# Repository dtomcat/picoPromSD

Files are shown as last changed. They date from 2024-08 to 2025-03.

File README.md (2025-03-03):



# picoPromSD
EEPROM reader/writer and OG Xbox Seagate Password retrieval for the Original Xbox that also decodes the EEPROM data

What will it do?

1. Backup the Xbox's EEPROM and save it to microSD card.
2. Can write an EEPROM backup saved to µSD card to the Xbox's EEPROM.  (has some checks to help prevent writing a bad backup to the EEPROM)
3. Decrypt the EEPROM and save the important information in plain text to the µSD card.
4. Can calculate the HDD password while backing up the EEPROM (for OEM Seagate and WD drives)
		- Requires preparing an additional file.  Video of process: [Video of Process](https://youtu.be/JSXaQWXcwFo?si=bOLGbLG80aQxxA59)
5. For OEM Seagate drives (ALL), It can grab the HDD password directly from the drive itself.  No need for EEPROM or XBOX.  [Video of Process](https://youtu.be/1lWm_fr0Neo?si=kcM-wwt6UB56qRjm)
6. For OEM Seagate drives (ALL), It can unlock the HDD directly from the drive itself.  No need for EEPROM or XBOX.  [Video of Slim](https://www.youtube.com/shorts/Nwhjg9Vyvl8), [Video of RJ](https://www.youtube.com/shorts/swidWJ0N5yo)
7. More features may be added later.
<br><br><br>
This project is based on the work from Ryzee119's ArduinoProm:

>ArduinoProm. An Arduino based Original Xbox EEPROM reader and writer.
>It can be used to recover a HDD key etc. <br><br>
>ArduinoProm is inspired and adapted upon the awesome work by Grimdoomer on PiPROM, now achievable on a <$3 Arduino board.
>See https://github.com/grimdoomer/PiPROM for the Original Raspberry Pi version!
>  
>**Use at your own risk**
>

>The firmware has been written around the Arduino Pro Micro Leonardo (5V/16Mhz). However I would expect it to work on any Arduino with a built in USB >bootloader/Virtual Comport support, and obviously I2C support.
>1. Open `ArduinoProm.ino` in [Arduino IDE](https://www.arduino.cc/en/main/software)
>2. Connect your Arduino to your PC and setup the IDE. An example below <br> Arduino IDE preview
>3. Hit the program button then confirm it compiles and programs successfully.
>
>
>By Ryzee119

This project uses code by Ryzee119, dx4m (from this [project](https://github.com/dx4m/Xbox-EEPROM-Utility)), and may contain code from various snippets from different forums (sorry lost my notes on who to thank).

This project is a continuation of my work from [ArdPromSD project](https://github.com/dtomcat/ArdPromSD).
This project was moved to an RP2040 MCU for more memory space.  This allowed me add the features I wanted to from the previous project, but ran out of program space to do so.  New features include better logging, eeprom decryption, as well as being able to retrieve the password from OEM seagate drives without the need for the original eeprom, original xbox, or even a PC!

SPECIAL THANKS!!!!<br>
Ryzee for his project above!<br>
Skye for all the HDD commands and knowledge! Invaluable addition to PPSD!<br>
Beta Testers:  Cato, Harcroft, Siktah

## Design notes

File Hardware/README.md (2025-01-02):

1.1 is the initial released version.  Those who backed the initial project and funded it have a limited edition 1.0a version (Thank you!).  This will not be released and is solely for the limited backers.  1.1 just has minor trace redesigns and the "Advanced users" port has been removed.  Version 1.5H has already been designed and as soon as it's tested, It will be uploaded.  I do not recommend building rev 1.1 as 1.5H has major changes to the board to allow for lower cost builds.  Functionally, they will be the same.  Enjoy!<br><br>

# Rev 1.1 - 12DEC2024
Initial Release (No Gerbers or Assembly info for this release.  1.5H and above will have them.)

# Rev 1.5H - 02JAN2025
Happy New Year!  1.5H released (rework done by Harcroft - Thank you!  Allows for lower cost build with same quality and funcionality) This is a full release with everything you need to build one, or have one assembled.

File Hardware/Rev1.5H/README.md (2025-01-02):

## Initial release of picoPromSD
Initial release that contains everything needed to either make or have one assembled
This revision is an edit from the first release.  All edits were done by Harcroft who put a lot of time in effort into find same quality alternate parts at lower costs so picoPromSD could be build at a lower cost without sacrificing quality or functionality! <br><br>

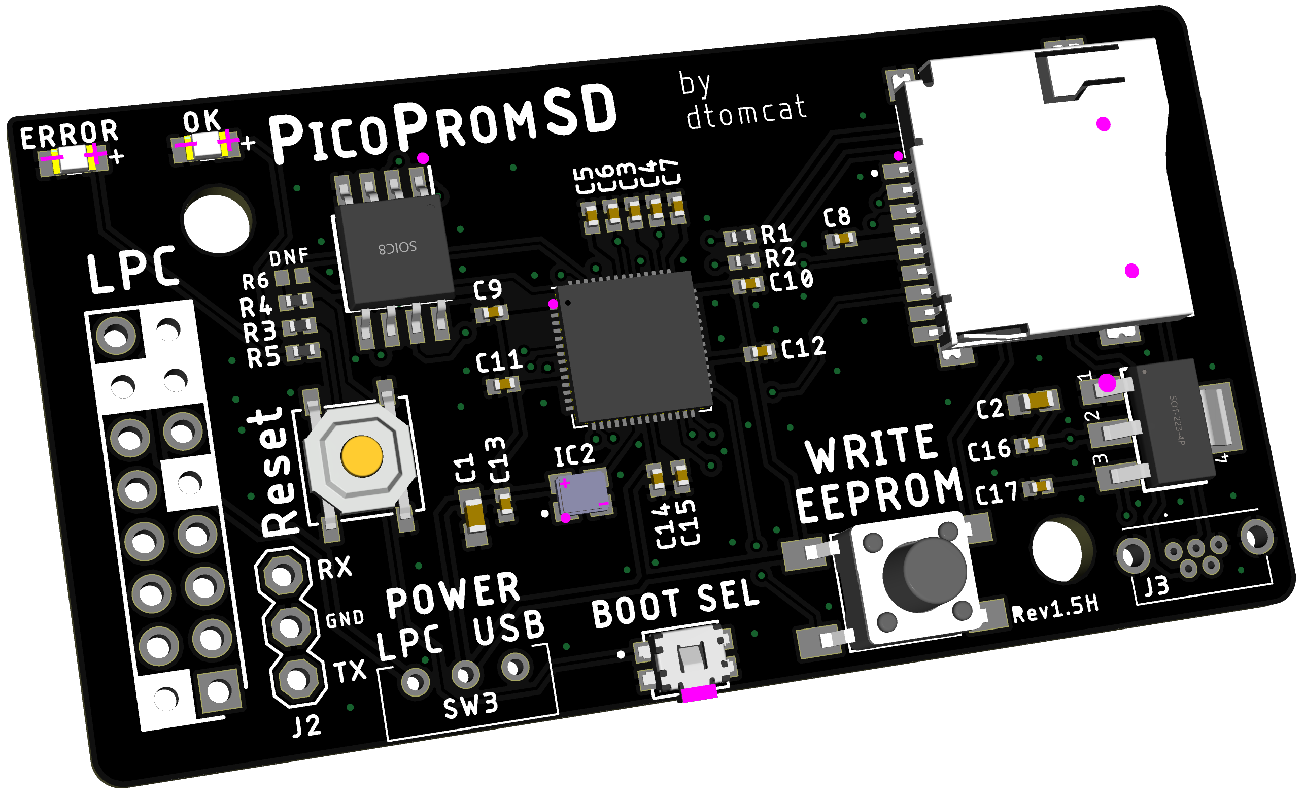
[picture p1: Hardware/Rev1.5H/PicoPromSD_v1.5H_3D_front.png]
picoPromSD
<br>
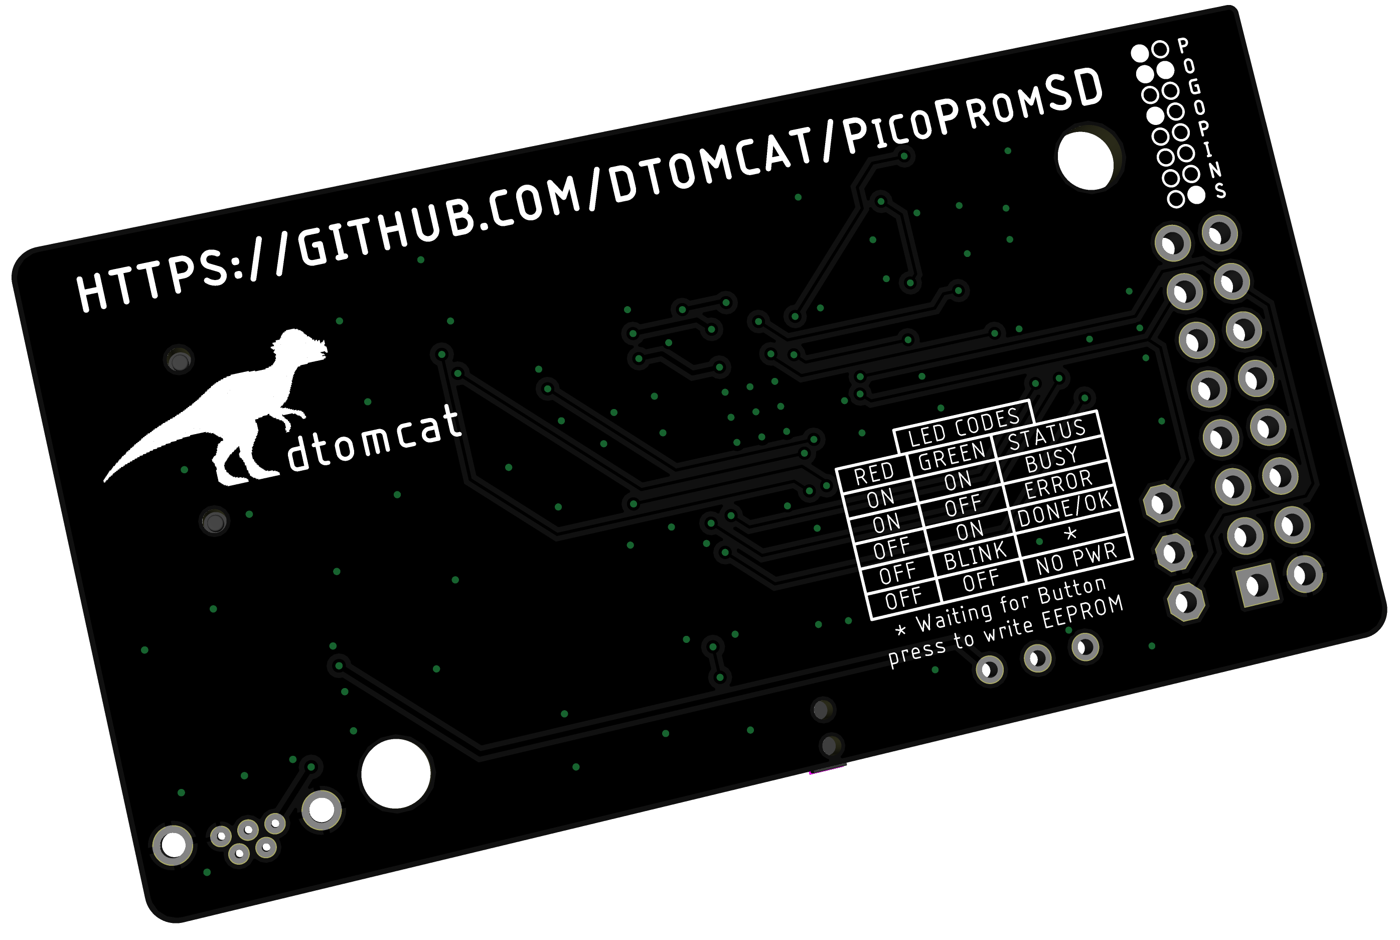
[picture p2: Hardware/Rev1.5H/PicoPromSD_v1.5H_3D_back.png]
picoPromSD
<br>

In the main Rev1.5H directory are all the files to edit the board as you want including library of all components.

### Gerbers
- Contains all files necessary to have the PCBs made at your preferred PCB house.<br><br>

### Assembly
- Contains all files necessary to have the PCBs made and assemble at your preferred PCB house. (was made for JLCPCB, but may work with others)
    - [PicoPromSD_v1.5H_JLC_PCBA_BOM.xlsx](Assembly/PicoPromSD_v1.5H_JLC_PCBA_BOM.xlsx) and [PicoPromSD_v1.5H_top_JLC_CPL.csv](Assembly/PicoPromSD_v1.5H_top_JLC_CPL.csv) are the files JLCPCB will ask for when selecting assembly.
    - [PicoPromSD_v1.5H_LCSC_THT_BOM.xlsx](Assembly/PicoPromSD_v1.5H_LCSC_THT_BOM.xlsx) is the parts you'll need (from LCSC) that are not a part of the assembly and will need to be hand soldered on.  These are through hole components and were purposely omitted from the assembly to save costs since through hole adds a considerable amount to assembly costs.
    - [PicoPromSD_v1.5H_Digikey_BOM.xlsx] contains a full BOM to allow you to order all the parts and hand assemble the entire board. (or would just like to use parts from Digikey instead of LCSC).

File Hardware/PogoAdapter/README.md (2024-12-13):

This is the STL for the pogoadapter.  Uses a 2x08 pin header and 5 pogo pins.   Highly recommend P75-E3 pogo pins.

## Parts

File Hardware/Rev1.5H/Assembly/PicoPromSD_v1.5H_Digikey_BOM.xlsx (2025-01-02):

Digikey Part Number | Quantity | Manufacturer Part Number | Customer Reference | Description | Pack Type 1
2648-SC0914(13)CT-ND | 1 | SC0914(13) | IC1 | IC MCU 32BIT EXT MEM 56QFN | Cut Tape (CT)
XC1426CT-ND | 1 | ECS-2033-120-BN | IC2 | XTAL OSC XO 12.0000MHZ CMOS SMD | Cut Tape (CT)
W25Q32JVSSIQ-ND | 1 | W25Q32JVSSIQ | IC3 | IC FLASH 32MBIT SPI/QUAD 8SOIC | Tube
497-1241-1-ND | 1 | LD1117S33CTR | IC4 | IC REG LINEAR 3.3V 800MA SOT223 | Cut Tape (CT)
2223-MSD-4-ACT-ND | 1 | MSD-4-A | J1 | MICRO SD CARD CONNECTOR, 9 POSIT | Cut Tape (CT)
2223-TS04-66-70-BK-100-SMT-ND | 1 | TS04-66-70-BK-100-SMT | SW1 | SWITCH TACTILE SPST-NO 0.05A 12V | Bag
CKN12221-1-ND | 1 | PTS526SK15SMTR2 LFS | SW2 | SWITCH TACTILE SPST-NO 0.05A 12V | Cut Tape (CT)
4809-SKSCLBE010CT-ND | 1 | SKSCLBE010 | SW4 | SWITCH TACTILE SPST-NO 0.05A 12V | Cut Tape (CT)
732-4986-1-ND | 1 | 150080VS75000 | GLED | LED GREEN CLEAR 0805 SMD | Cut Tape (CT)
732-4984-1-ND | 1 | 150080RS75000 | RLED | LED RED CLEAR 0805 SMD | Cut Tape (CT)
1276-1192-1-ND | 10 | CL10A106KP8NNNC | C1, C2 | CAP CER 10UF 10V X5R 0603 | Cut Tape (CT)
1276-1010-1-ND | 10 | CL05A105KQ5NNNC | C3, C4 | CAP CER 1UF 6.3V X5R 0402 | Cut Tape (CT)
1276-1001-1-ND | 20 | CL05B104KO5NNNC | C5 - C17 | CAP CER 0.1UF 16V X7R 0402 | Cut Tape (CT)
YAG3085CT-ND | 10 | RC0402FR-0727R4L | R1, R2 | RES 27.4 OHM 1% 1/16W 0402 | Cut Tape (CT)
311-820LRCT-ND | 10 | RC0402FR-07820RL | R3 | RES 820 OHM 1% 1/16W 0402 | Cut Tape (CT)
311-1.00KLRCT-ND | 10 | RC0402FR-071KL | R4, R5 | RES 1K OHM 1% 1/16W 0402 | Cut Tape (CT)
1849-1003-ND | 1 | PR20203VBNN | J2 | CONN HEADER VERT 3POS 2.54MM | Bag
2073-USB3145-30-1-ACT-ND | 1 | USB3145-30-1-A | J3 | MICRO B SKT, VERTICAL, TH, 30", | Cut Tape (CT)
732-61301621821-ND | 1 | 61301621821 | LPC | WR-PHD 2.54 MM DUAL SOCKET HEADE | Tray
679-1849-ND | 1 | MHSS1105 | SW3 | SWITCH SLIDE SPDT 300MA 6V | Bulk

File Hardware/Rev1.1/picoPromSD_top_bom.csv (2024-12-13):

Comment | Designator | Footprint | LCSC Part #
1K | GLED R5 R6 RLED R4 | R0402
1u | C1 C4 | C0402
10uF | C18 | C0603
27R | R1 R2 | R0402
100n | C2 C3 C5 C6 C7 C8 C9 C10 C11 C12 C13 C14 C15 C16 C17 | C0402
DNF 10K | R3 | R0402
EVQ-P7A01P | S4 | EVQP7J01P
LD1117S33TR | IC4 | SOT223
MEM2075-00-140-01-A | J1 | MEM20750014001A
RP2040-QFN56 | IC1 | RP2040-QFN-56
SIT2001B | IC2 | SOT95P280X130-5N
TL6330AF200Q | S2 | TL6330AF200Q
TS04-66-70-BK-100-SMT | S1 | SW_TS04-66-70-BK-100-SMT
W25Q32JVSSIQ_TR | IC3 | SOIC127P790X216-8N

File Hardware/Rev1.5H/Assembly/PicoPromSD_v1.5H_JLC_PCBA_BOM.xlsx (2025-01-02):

Comment | Designator | Footprint | JLCPCB Part #（optional）
RP2040 | IC1 | LQFN-56(7x7) | C2040
S2D12.000000B20F30T | IC2 | SMD2520-4P | C387449
W25Q32JVSSIQ | IC3 | SOIC-8-208mil | C82344
LD1117S33CTR | IC4 | SOT-223-4 | C35879
WQ21801-B2180-7F | J1 | SMD | C2836427
TS-1102SD-A-G-R | SW1 | SMD | C3010210
GT-TC084B-H015-L5 | SW2 | SMD | C778173
SKSCLBE010 | SW4 | SMD | C115361
KT-0805G | GLED | 0805 | C2297
NCD0805R1 | RLED | 0805 | C84256
CL10A106KP8NNNC | C1,C2 | 0603 | C19702
CL05A105KA5NQNC | C3,C4 | 0402 | C52923
CL05B104KO5NNNC | C5,C6,C7,C8,C9,C10,C11,C12,C13,C14,C15,C16,C17 | 0402 | C1525
RC0402FR-0727R4L | R1,R2 | 0402 | C274349
RC0402FR-07820RL | R3 | 0402 | C137933
0402WGF1001TCE | R4,R5 | 0402 | C11702

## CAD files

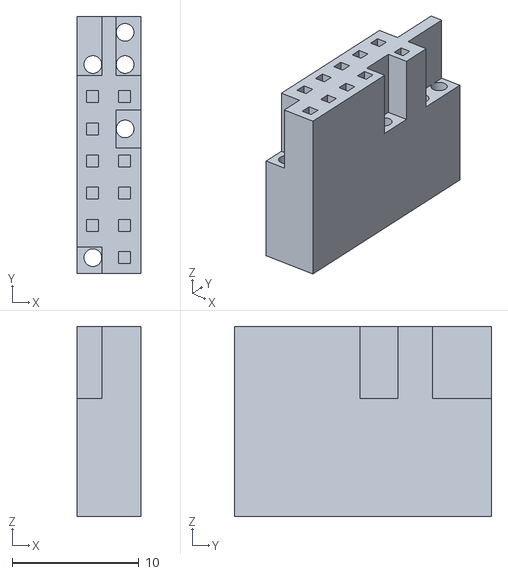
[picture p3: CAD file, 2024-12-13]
Hardware/PogoAdapter/Pin2PogoPico v3.stl
5.04 x 20.3 x 15.0

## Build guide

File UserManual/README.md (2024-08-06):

Still a work in progress... (Pogo Pin Section needs updated, need to add a lot more info)

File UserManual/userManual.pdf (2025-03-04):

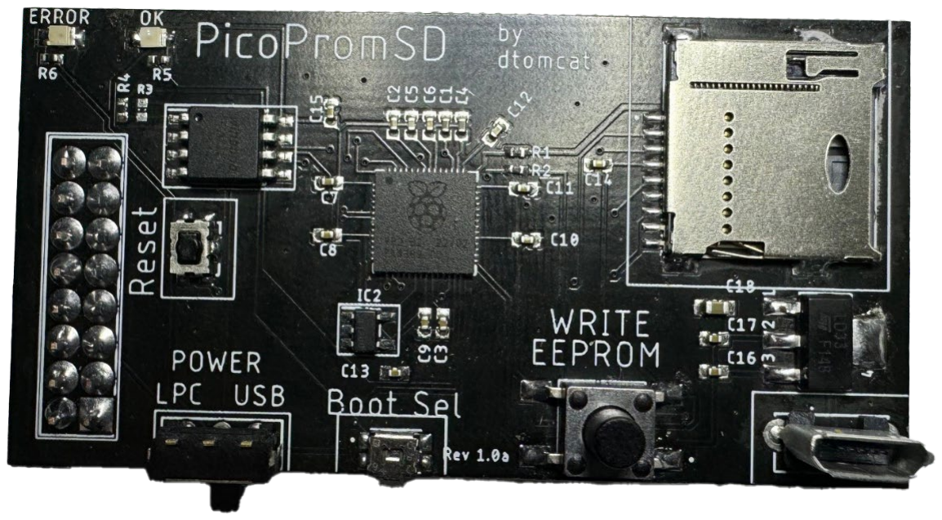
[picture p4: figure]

# PicoPromSD User Manual

## Version 1.0

01/04/2024

Pachy Software | Introduction
UM Version 1.0 | 2 | PicoPromSD

Table of Contents

Pachy Software | Introduction
UM Version 1.0 | 3 | PicoPromSD

# 1. Introduction

This User Manual (UM) provides the information necessary for effective use of PicoPromSD.

## 1.1 Overview

The PicoPromSD was designed as a tool to backup and restore EEPROM data in the original Microsoft Xbox. Upon plugging in the PicoPromSD into the Xbox’s LPC port, it will automatically backup the EEPROM data to inserted microSD card in the “EPBACKUP” folder. This only takes a second. If an “eeprom.bin” file is found in the “WRITEEP” folder, you will be given the option to write that file onto the EEPROM chip on the Xbox motherboard. Ensure you read over this entire manual before using your PicoPromSD for the first time.

Pachy Software | Getting Started
UM Version 1.0 | 4 | PicoPromSD

# 2. Getting Started

## 2.1 Cautions & Warnings

This tool has the potential to damage your Xbox and turn it into a paperweight. If mishandled, it could corrupt your EEPROM which could cause the Xbox to no longer function. You take all the risks associated with using the PicoPromSD and no guarantees are made.

## USE AT YOUR OWN RISK

## 2.2 Set-up Considerations

To use PicoPromSD, you will need a microSD card that is formatted with FAT32 filesystem. FAT16 should also work but not tested.
You will be required to disassemble your Xbox (not covered in the manual) to access the LPC port on your Xbox.
The easiest way to use PicoPromSD, is to have a 2x8 pin header soldered into the Xbox’s LPC port. While this is not necessary, it will allow the safest and easiest connection. The LPC port does not have to be rebuilt for 1.6 versions of motherboards; however, if soldering a pin header onto the motherboard, it’s recommended to go ahead with the rebuild for future use.

Pachy Software | Using the System

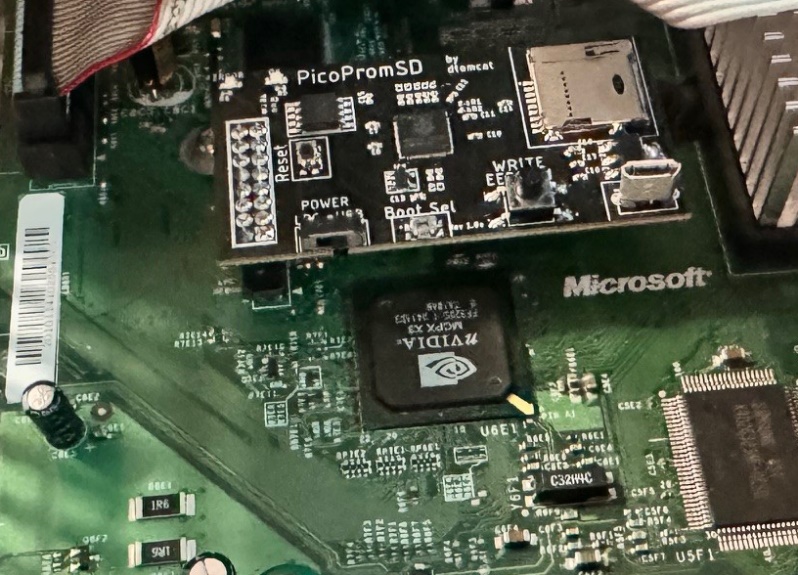
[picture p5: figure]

UM Version 1.0 | 5 | PicoPromSD

# 3. Using the System

The following sub-sections provide step-by-step instructions on how to use the various functions or features of the PicoPromSD. Figure 2 in this section will identify the LEDs mentioned in this section.

## 3.1 Backing up the EEPROM

Backing up the EEPROM is easy and requires very little from the user. This guide will assume your LPC port on your Xbox has a pin header installed as recommended in section 2.2.
1. Insert the FAT32/FAT16 formatted microSD card into the PicoPromSD
2. With the Xbox POWERED OFF and Power switch is on USB (to the right), place the PicoPromSD onto the pin header on the LPC port. Place it so that the microSD and button are on the right-hand side of the LPC port and are closer to the center of the Xbox’s motherboard (see Figure 1).
3. Power on the Xbox.
a. After power is stable (if D0/LFrame is grounded, let the Xbox FRAG), Flip the power switch on the PicoPromSD to LPC.
b. When power is applied, you will see both the green and red LEDs light up. This means that the backup is in process.
c. After a second, the red LED will go out and the green will stay on. This means that the backup was successful. If the green LED goes out and red stays on, then there was an error. Check the microSD card and try again. If the problem persists, check the log written to the SD for possible errors. If no log has been written, then the SD card may be the issue.
4. Turn off power to your Xbox and flip the power switch to USB, then remove the PicoPromSD.
a. Your backup will be on the microSD card under the epbackup folder. You can backup multiple times. Each backup name is incremented, so you can backup multiple systems without needing to change microSD card. (Backups are named the Xbox’s Serial number or eeprom.bin (if serial number cannot be determined), subsequent backups of same system will append a 1,2,3, etc… to the file name.)
5. Backup is complete.

Figure 1.

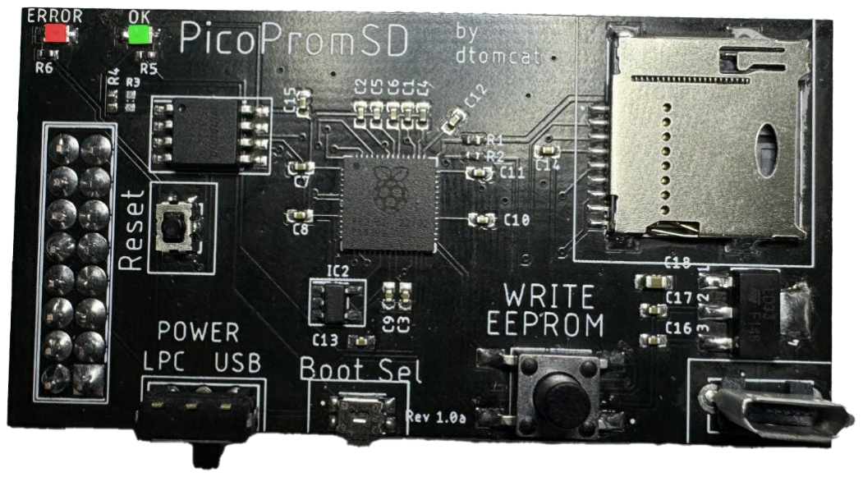
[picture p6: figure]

UM Version 1.0 | 6 | PicoPromSD

## 3.2 Writing to the EEPROM

Writing to your EEPROM is a little bit more involved (on purpose). It’s important to note that the PicoPromSD does not validate nor verify the eeprom.bin provided by you. If you provide a corrupt eeprom.bin, it will write the corrupt eeprom.bin and therefore… CORRUPT your EEPROM. Caution must be taken to ensure you provide a valid eeprom.bin.
Please note, that eeprom.bin file will be deleted from the “WRITEEP” folder (discussed later). The eeprom.bin files inside the EPBACKUP folder will not be touched. Please ensure you have a backup of the eeprom.bin file you place in the “WRITEEP” folder.
To write to your EEPROM:
1. On the microSD card you’re using
a. Create a new folder in the root directory named “WRITEEP”
b. Copy your eeprom.bin (that you validated and verified) into the “WRITEEP” folder.
c. Now follow the instructions in section 3.1 through 3.1.3. Do not turn off the Xbox. After 3.1.3, return here.
2. After the backup, if the microSD card was prepared correctly, the PicoPromSD’s green LED will flash rapidly. This informs you that it sees the eeprom.bin in the WRITEEP folder and is ready to write the EEPROM.
a. CAUTION: the next part can kill your Xbox. Do not proceed unless you know what you are doing. This will overwrite your EEPROM with the data you provided. If that data is corrupt… so will your EEPROM. PROCEED AT YOUR OWN RISK.
3. When ready to Write, and the green LED is flashing rapidly, Press the “WRITE EEPROM” button on the PicoPromSD.
a. When complete, the green LED is will stay on solid, and the write process is complete. NOTE: The eeprom.bin file is now deleted from the “WRITEEP” folder. This is to ensure you do not accidentally write that file to another Xbox.
4. Write Process is now complete.

Figure 2.

UM Version 1.0 | 7 | PicoPromSD

## 3.3 Reading/Writing the EEPROM without a Pin Header

It is possible to read from and write to your EEPROM without a pin header installed on your Xbox. One example will be given in this section (pogo pins). While reading from your EEPROM with this method is relatively safe, it is not recommended for writing to your EEPROM. This method basically uses pressure to make the electrical connections between the PicoPromSD and Xbox LPC port as you press the pogo pins into place. Reading data from the EEPROM is relatively quick and, if done incorrectly, results in an error or a corrupted eeprom.bin stored to the SD card. Writing data to the EEPROM is relatively time-consuming and requires a very stable electrical connection by comparison. Failing to write the EEPROM correctly will permanently damage your xbox. If enough pressure can be exerted the entire time (while pressing the “write EEPROM” button and throughout the entire process) this method can be used for reading and writing. Again… This process isn’t recommended for writing… and note the chance of your backup being corrupted as well.

## 3.3.1 Cautions with pogo pin method

CAUTIONS/WARNINGS:
1. If the pogo pins are not placed on the correct LPC port vias/pads, you can damage the PicoPromSD and/or your Xbox motherboard. Ensure proper placement. Damage can occur while the Xbox is powered OFF but plugged into a wall outlet.
2. Take care not to exert too much pressure on the pogo pins as damage to boards/pins can occur. Only enough force to compress the internal springs is needed.
3. Not exerting enough force will result in poor connection. During the reading stage… this can result in corrupted backup files. During the writing stage, this can cause damage to your Xbox resulting in the Xbox not being able to boot.
4. If the LPC appears dirty, You may need to clean the area to ensure a good electrical connection.

## 3.3.2 Making a Pogo Pin attachment

There are many ways to make a pogo pin attachment for the PicoPromSD. How you do so is up to you. There is a 3D model that can be printed to aid in this step.
You will need the following:
1. 1 3D printed part
2. 1 2x8 pin header
3. 5 Pogo pins (P75-E3 Spring Test Probe)
4. Soldering Iron/Solder
This requires soldering in small places. It is not recommended for those who are not comfortable with soldering. Heat and plastic do not mix! If you are not comfortable or careful, you will melt the plastic and may make the piece unusable.

### 3.3.2.1 Assembly Instructions

1. Insert pin header (use side with shorter pins) into 3D printed part. Use the side with square holes.
2. Insert pogo pins (end with smallest diameter) into opposite side of 3D printed part. Ensure the ends of pogo pins and pin header touch in the visible voids of 3D printed part.

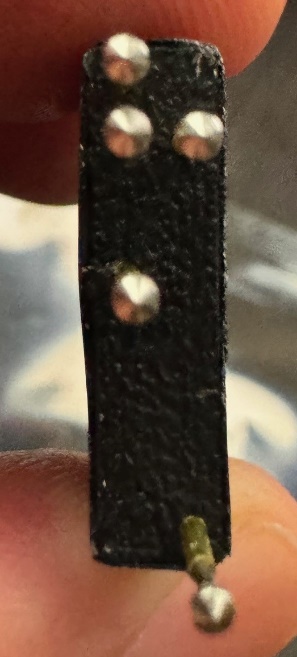
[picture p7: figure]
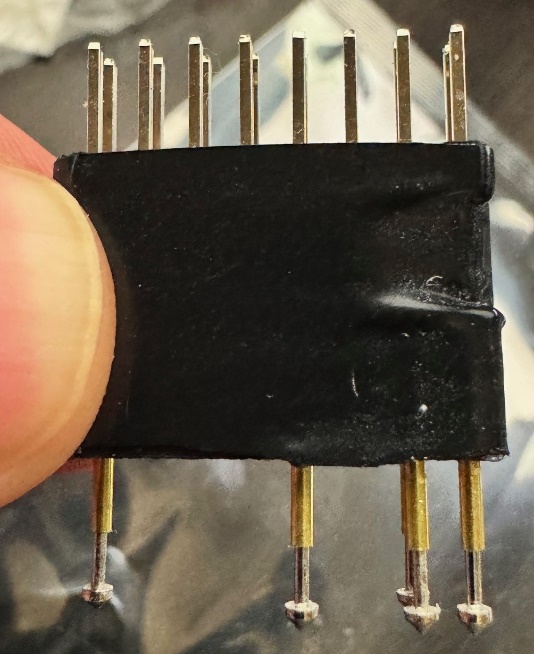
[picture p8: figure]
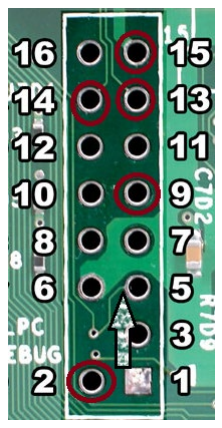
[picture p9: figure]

UM Version 1.0 | 8 | PicoPromSD
3. With Pin header fully inserted and touch pogo pins, solder the point where pogo pins/pin header meet (all 5 locations). Take caution not to melt the plastic.
4. Attachment is ready for use. You can use a multimeter to ensure a good connection exists between pin header and pogo pins. (Figure 3 and 4) show a completed pogo pin attachment.
5. You’ll insert the pin header side into the PicoPromSD. The side with the group of 3 pogo pins (right side of Figure 4) goes towards the side with the 2 LEDs (top of the board) and the side with single pin goes towards the side with power switch (can see 3 pins from power switch under LED Codes chart).
Figure 3 | Figure 4

## 3.3.3 Using Pogo Pin attachment

Using the pogo pin attachment takes a little bit of finesse, but not too difficult. Refer to figure 5 for pin numbering for the LPC port. This section assumes the pogo pin attachment is already connected to the PicoPromSD (refer to 3.3.2.1.5).
WARNING: Improper placement may damage the Xbox motherboard and/or PicoPromSD. Ensure proper alignment before applying any pressure.

Figure 5

UM Version 1.0 | 9 | PicoPromSD

### 3.3.3.1 Steps of use

1. Ensure Xbox is powered off. (This is not necessary, but safest way)
2. Place the 2 parallel pogo pins on LPC pins 14 and 13 keeping the remaining two pins off LPC port.
3. Rotate PicoPromSD to allow remaining pins to contact LPC port pins 6 and 2.
4. Apply slight and even pressure ensure pogo pins compress (but not fully compress). This will ensure a good connection between PicoPromSD and Xbox.
5. Keep slight (and even) pressure throughout the remaining processes.
6. Follow steps for reading/writing as desired (sections 3.1/3.2 respectively).

A video of this in action can be seen here: https://dtomc.at/PicoPromSDPogoPin
3D Print files can be found here: https://github.com/dtomcat/PicoPromSD

## 3.4 Reading the Password from OG XBOX Seagate Drives

This section requires that you have updated your board to at least firmware 2.2 or higher. This will work with all OG Xbox Seagate drives (slim and rubber jacketed). This functionality will grab the hard drive’s password (not HDD key like with EEPROM). This password can be used to unlock the drive using software like FatXplorer (https://fatxplorer.eaton-works.com).

## 3.4.1 Required Items

1. 3 wires (or self made adapter) each with a male end and a female end
2. OG Xbox Seagate Hard Drive
3. PicoPromSD (Firmware 2.2 or higher)

## 3.4.2 Connections

Connect the 3 wires using figures 6 and 7. You’ll connect the TX’s together, RX’s together, and GND’s together. NOTE: These are not the pin names for each device! They are labelled this way to eliminate confusion. Do NOT apply power to either device while connecting them together.

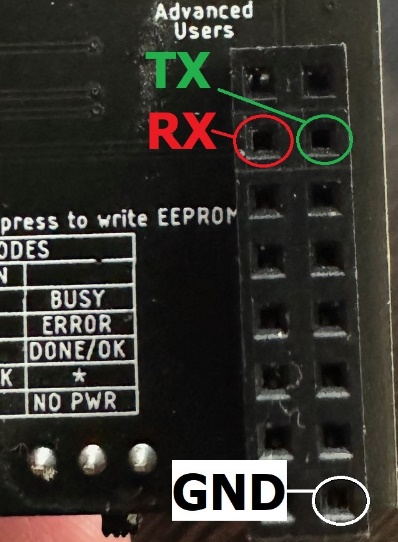
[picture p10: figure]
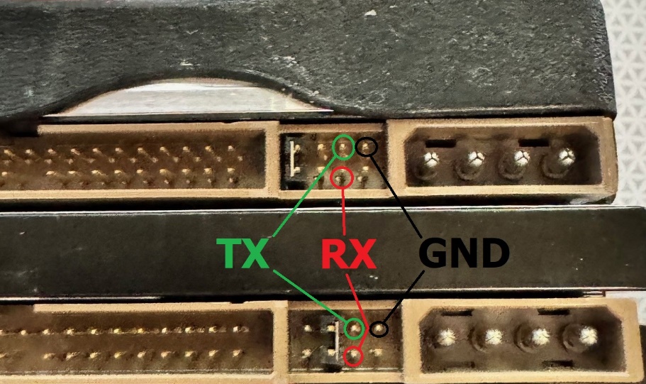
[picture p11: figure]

UM Version 1.0 | 10 | PicoPromSD
Figure 6 | Figure 7

## 3.4.3 Getting the Password

WARNING: Ensure both the HDD and picoPromSD are powered off.
1. Ensure that picoPromSD and HDD are powered off
2. Connect wires in accordance with section 3.4.2
3. Hold the “WRITE EEPROM” button on the picoPromSD
4. Apply power to picoPromSD while continuing to hold “WRITE EEPROM”
a. Power will come from USB port for this section. You can use USB connected to a computer, power brick, or battery pack.
5. You will see the Red and Green LEDs alternating; indicating you are in HDD password mode. (you can release the “WRITE EEPROM” button at this time)
6. Wait until the Green LED remains on steadily
a. This indicates that the picoPromSD is ready for the HDD to be powered on
7. Apply power to the HDD
a. You will see both red and green LEDs light up and remain on; indicating that the picoPromSD is communicating with the HDD
8. Wait for the Red LED to turn off and Green remain on. This indicates that the process is complete
a. If Green LED turns off and Red LED remains on… This indicates an Error occurred. You can try again from step 1
9. Turn off power to both the picoPromSD and the HDD
a. All data from the process will be stored on microSD card under “HDDPass” folder

## 3.5 Unlocking OG XBOX Seagate Drives

This section requires that you have updated your board to at least firmware 3.0 or higher. This will work with all OG Xbox Seagate drives (slim and rubber jacketed). This functionality will unlock the hard drive.
WARNING: This will nuke the password (set to all zeros) for the Slim version. The process will back up the password… but it will then be nuked.
For Rubber Jacket drives, the drive is set to an unlocked state and the password is unaffected.

UM Version 1.0 | 11 | PicoPromSD

## 3.5.1 Required Items

1. 3 wires (or self made adapter) each with a male end and a female end
2. OG Xbox Seagate Hard Drive
3. PicoPromSD (Firmware 3.0 or higher)

## 3.5.2 Connections

Connect the 3 wires using figures 6 and 7 above. You’ll connect the TX’s together, RX’s together, and GND’s together. NOTE: These are not the pin names for each device! They are labelled this way to eliminate confusion. Do NOT apply power to either device while connecting them together.

## 3.5.3 Unlocking the drive

WARNING: Ensure both the HDD and picoPromSD are powered off.
1. Ensure that picoPromSD and HDD are powered off
2. Connect wires in accordance with section 3.5.2
3. Hold the “WRITE EEPROM” button on the picoPromSD
4. Apply power to picoPromSD while continuing to hold “WRITE EEPROM”
a. Power will come from USB port for this section. You can use USB connected to a computer, power brick, or battery pack.
5. You will see the Red and Green LEDs alternating; indicating you are in HDD password mode.
a. Keep holding the “WRITE EEPROM” button until the LEDs start alternating faster.
b. You can then release the “WRITE EEPROM” button and the PicoPromSD is now in HDD unlock mode.
6. Wait until the Green LED remains on steadily
a. This indicates that the picoPromSD is ready for the HDD to be powered on
7. Apply power to the HDD
a. You will see both red and green LEDs light up and remain on; indicating that the picoPromSD is communicating with the HDD
8. Wait for the Red LED to turn off and Green remain on. This indicates that the process is complete
a. If Green LED turns off and Red LED remains on… This indicates an Error occurred. You can try again from step 1
9. Turn off power to both the picoPromSD and the HDD
a. All data from the process will be stored on microSD card under “HDDPass” folder
b. The HDD should now be unlocked.

Pachy Software | Upgrading the Firmware
UM Version 1.0 | 12 | PicoPromSD

# 4. Upgrading the Firmware

The following sub-sections provide step-by-step instructions on how to upgrade the firmware of the PicoPromSD.

## 4.1.1 Where to get the Firmware

The firmware will be hosted on my GitHub repository. The firmware will be listed as a UF2 file. Download this file and save it for later use. The current firmware as of this manual is 2.2. GitHub link: https://www.github.com/dtomcat/picoPromSD Firmware folder can be found here (https://github.com/dtomcat/picoPromSD/tree/main/firmware)

## 4.1.2 Upgrading the Firmware

Ensure you grabbed the firmware file from section 4.1.1.
1. Remove picoPromSD from the Xbox if connected and remove any USB cords connected
2. Slide the power switch on picoPromSD to the “LPC” side
a. This ensures no power will be applied to the picoPromSD prematurely
3. Plug the micro USB cable into the picoPromSD and connect to your Computer
4. Hold the “Boot Sel” button
5. While continuing to hold the “Boot Sel” button, Slide the power switch to “USB”
a. You should see a folder pop up (windows) with two files in it:
i. INDEX.HTM
ii. INFO_UF2.TXT
6. Place the UF2 file you downloaded in section 4.1.1 into this folder that popped up.
a. If no folder popped up, you may have to open it manually depending on the settings in windows.
7. After the file uploads, the picoPromSD will automatically reboot
8. Congratulations… Your picoPromSD’s firmware has been updated.

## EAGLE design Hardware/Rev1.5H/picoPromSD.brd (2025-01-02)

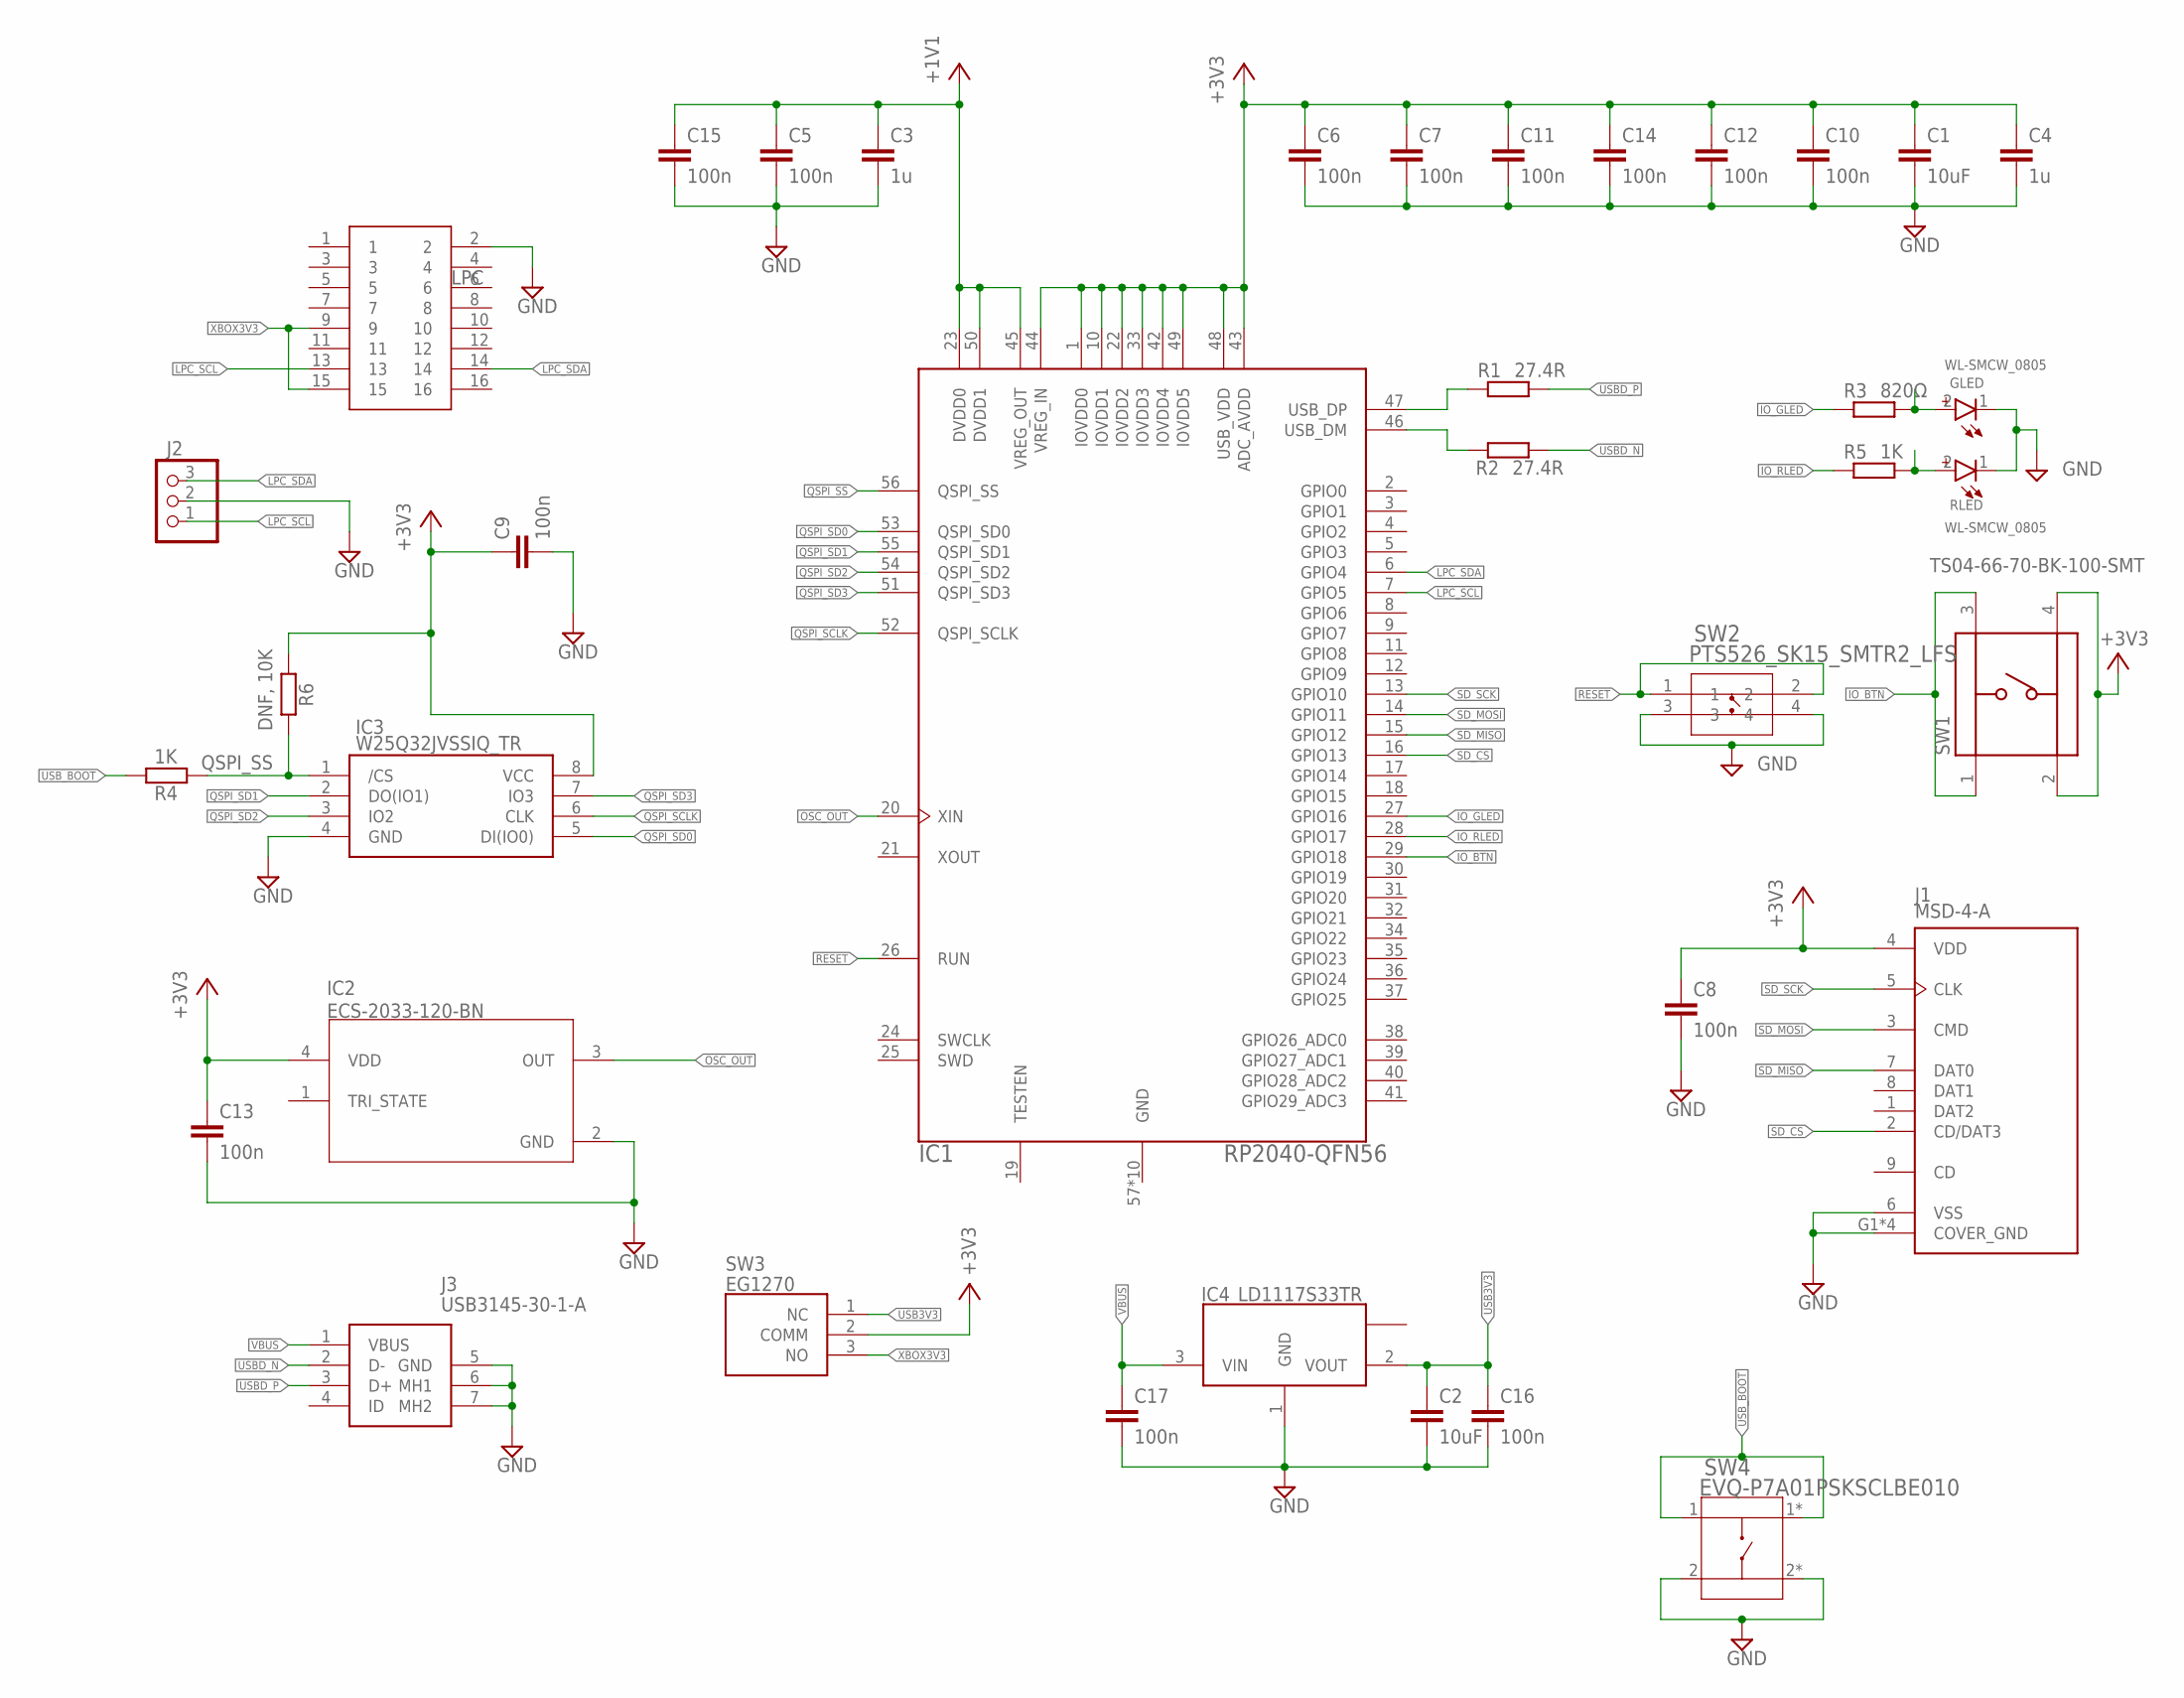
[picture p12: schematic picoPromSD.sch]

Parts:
C1, C2: 10uF; C0603
C3, C4: 1u; C0402
C5, C6, C7, C8, C9, C10, C11, C12, C13, C14, C15, C16, C17: 100n; C0402
GLED: WL-SMCW_0805
IC1: RP2040-QFN56; RP2040-QFN-56
IC2: ECS-2033-120-BN; OSC_ECS-2033-120-BN
IC3: W25Q32JVSSIQ_TR; SOIC127P790X216-8N
IC4: LD1117S33TR; SOT223
J1: MSD-4-A; CUI_MSD-4-A
J2: PINHEAD_2.54MM_1X3
J3: USB3145-30-1-A; USB3145301A
LPC: PINHEAD_2.54MM_2X8
R1, R2: 27.4R; R0402
R3: 820Ω; R0402
R4, R5: 1K; R0402
R6: DNF, 10K; R0402
RLED: WL-SMCW_0805
SW1: TS04-66-70-BK-100-SMT; SW_TS04-66-70-BK-100-SMT
SW2: PTS526_SK15_SMTR2_LFS; SMT_FS
SW3: EG1270
SW4: EVQ-P7A01PSKSCLBE010; SKSCLBE010

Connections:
+3V3: C1.1, C4.1, C6.1, C7.1, C8.1, C9.1, C10.1, C11.1, C12.1, C13.1, C14.1, IC1.1 (IOVDD0), IC1.10 (IOVDD1), IC1.22 (IOVDD2), IC1.33 (IOVDD3), IC1.42 (IOVDD4), IC1.43 (ADC_AVDD), IC1.44 (VREG_IN), IC1.48 (USB_VDD), IC1.49 (IOVDD5), IC2.4 (VDD), IC3.8 (VCC), J1.4 (VDD), R6.2, SW1.2, SW1.4, SW3.2 (COMM)
GND: C1.2, C2.2, C3.2, C4.2, C5.2, C6.2, C7.2, C8.2, C9.2, C10.2, C11.2, C12.2, C13.2, C14.2, C15.2, C16.2, C17.2, GLED.1 (-), IC1.57 (GND), IC1.58 (GND), IC1.59 (GND), IC1.60 (GND), IC1.61 (GND), IC1.62 (GND), IC1.63 (GND), IC1.64 (GND), IC1.65 (GND), IC1.66 (GND), IC2.2 (GND), IC3.4 (GND), IC4.1 (GND), J1.6 (VSS), J1.G1 (COVER_GND), J1.G2 (COVER_GND), J1.G3 (COVER_GND), J1.G4 (COVER_GND), J2.2, J3.5 (GND), J3.6 (MH1), J3.7 (MH2), LPC.2, RLED.1 (-), SW2.3, SW2.4, SW4.2, SW4.2* (!)
IO_BTN: IC1.29 (GPIO18), SW1.1, SW1.3
IO_GLED: IC1.27 (GPIO16), R3.1
IO_GLED2: GLED.2 (+), R3.2
IO_RLED: IC1.28 (GPIO17), R5.1
IO_RLED2: R5.2, RLED.2 (+)
LPC_SCL: IC1.7 (GPIO5), J2.1, LPC.13
LPC_SDA: IC1.6 (GPIO4), J2.3, LPC.14
OSC_OUT: IC1.20 (XIN), IC2.3 (OUT)
PUSBD_N: IC1.46 (USB_DM), R2.1
PUSBD_P: IC1.47 (USB_DP), R1.1
QSPI_SCLK: IC1.52 (QSPI_SCLK), IC3.6 (CLK)
QSPI_SD0: IC1.53 (QSPI_SD0), IC3.5 (DI(IO0))
QSPI_SD1: IC1.55 (QSPI_SD1), IC3.2 (DO(IO1))
QSPI_SD2: IC1.54 (QSPI_SD2), IC3.3 (IO2)
QSPI_SD3: IC1.51 (QSPI_SD3), IC3.7 (IO3)
QSPI_SS: IC1.56 (QSPI_SS), IC3.1 (/CS), R4.2, R6.1
RESET: IC1.26 (RUN), SW2.1, SW2.2
SD_CS: IC1.16 (GPIO13), J1.2 (CD/DAT3)
SD_MISO: IC1.15 (GPIO12), J1.7 (DAT0)
SD_MOSI: IC1.14 (GPIO11), J1.3 (CMD)
SD_SCK: IC1.13 (GPIO10), J1.5 (CLK)
USB3V3: C2.1, C16.1, IC4.2 (VOUT), SW3.1 (NC)
USBD_N: J3.2 (D-), R2.2
USBD_P: J3.3 (D+), R1.2
USB_BOOT: R4.1, SW4.1, SW4.1* (!_2)
VBUS: C17.1, IC4.3 (VIN), J3.1 (VBUS)
VCC: C3.1, C5.1, C15.1, IC1.23 (DVDD0), IC1.45 (VREG_OUT), IC1.50 (DVDD1)
XBOX3V3: LPC.9, LPC.15, SW3.3 (NO)

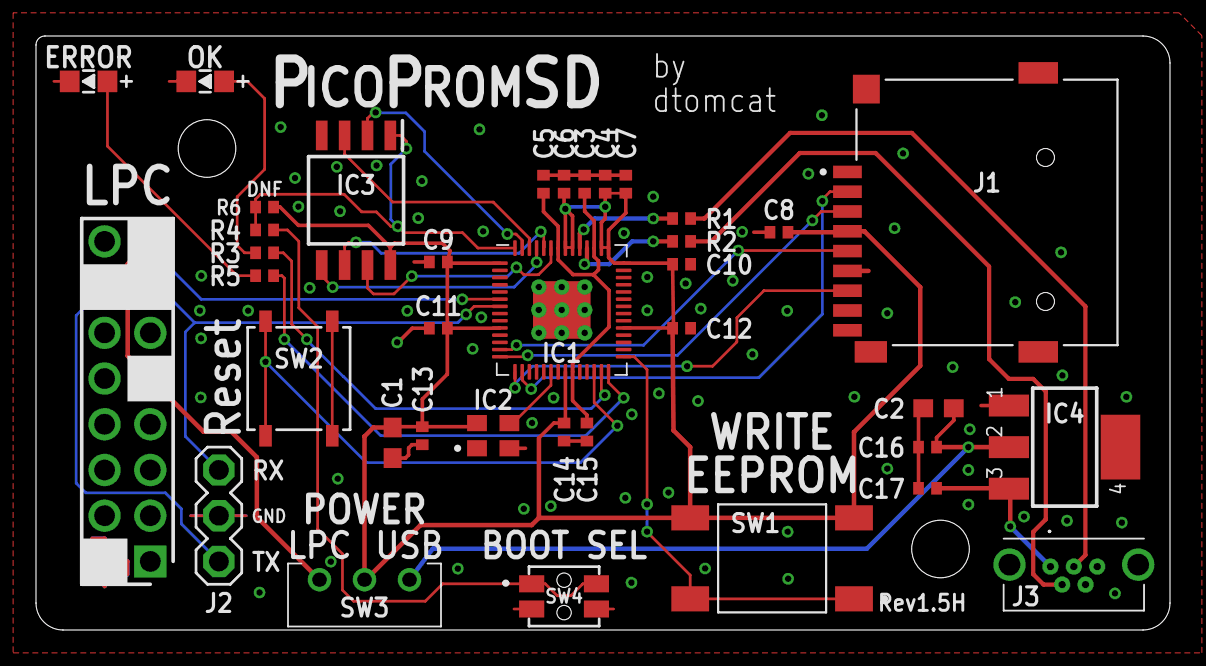
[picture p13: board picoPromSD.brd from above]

Board: 2 copper layers, 63.0 x 33.0 mm, 38 parts (1 on the bottom side), 30 nets.

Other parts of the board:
U$1: POGO_SILK

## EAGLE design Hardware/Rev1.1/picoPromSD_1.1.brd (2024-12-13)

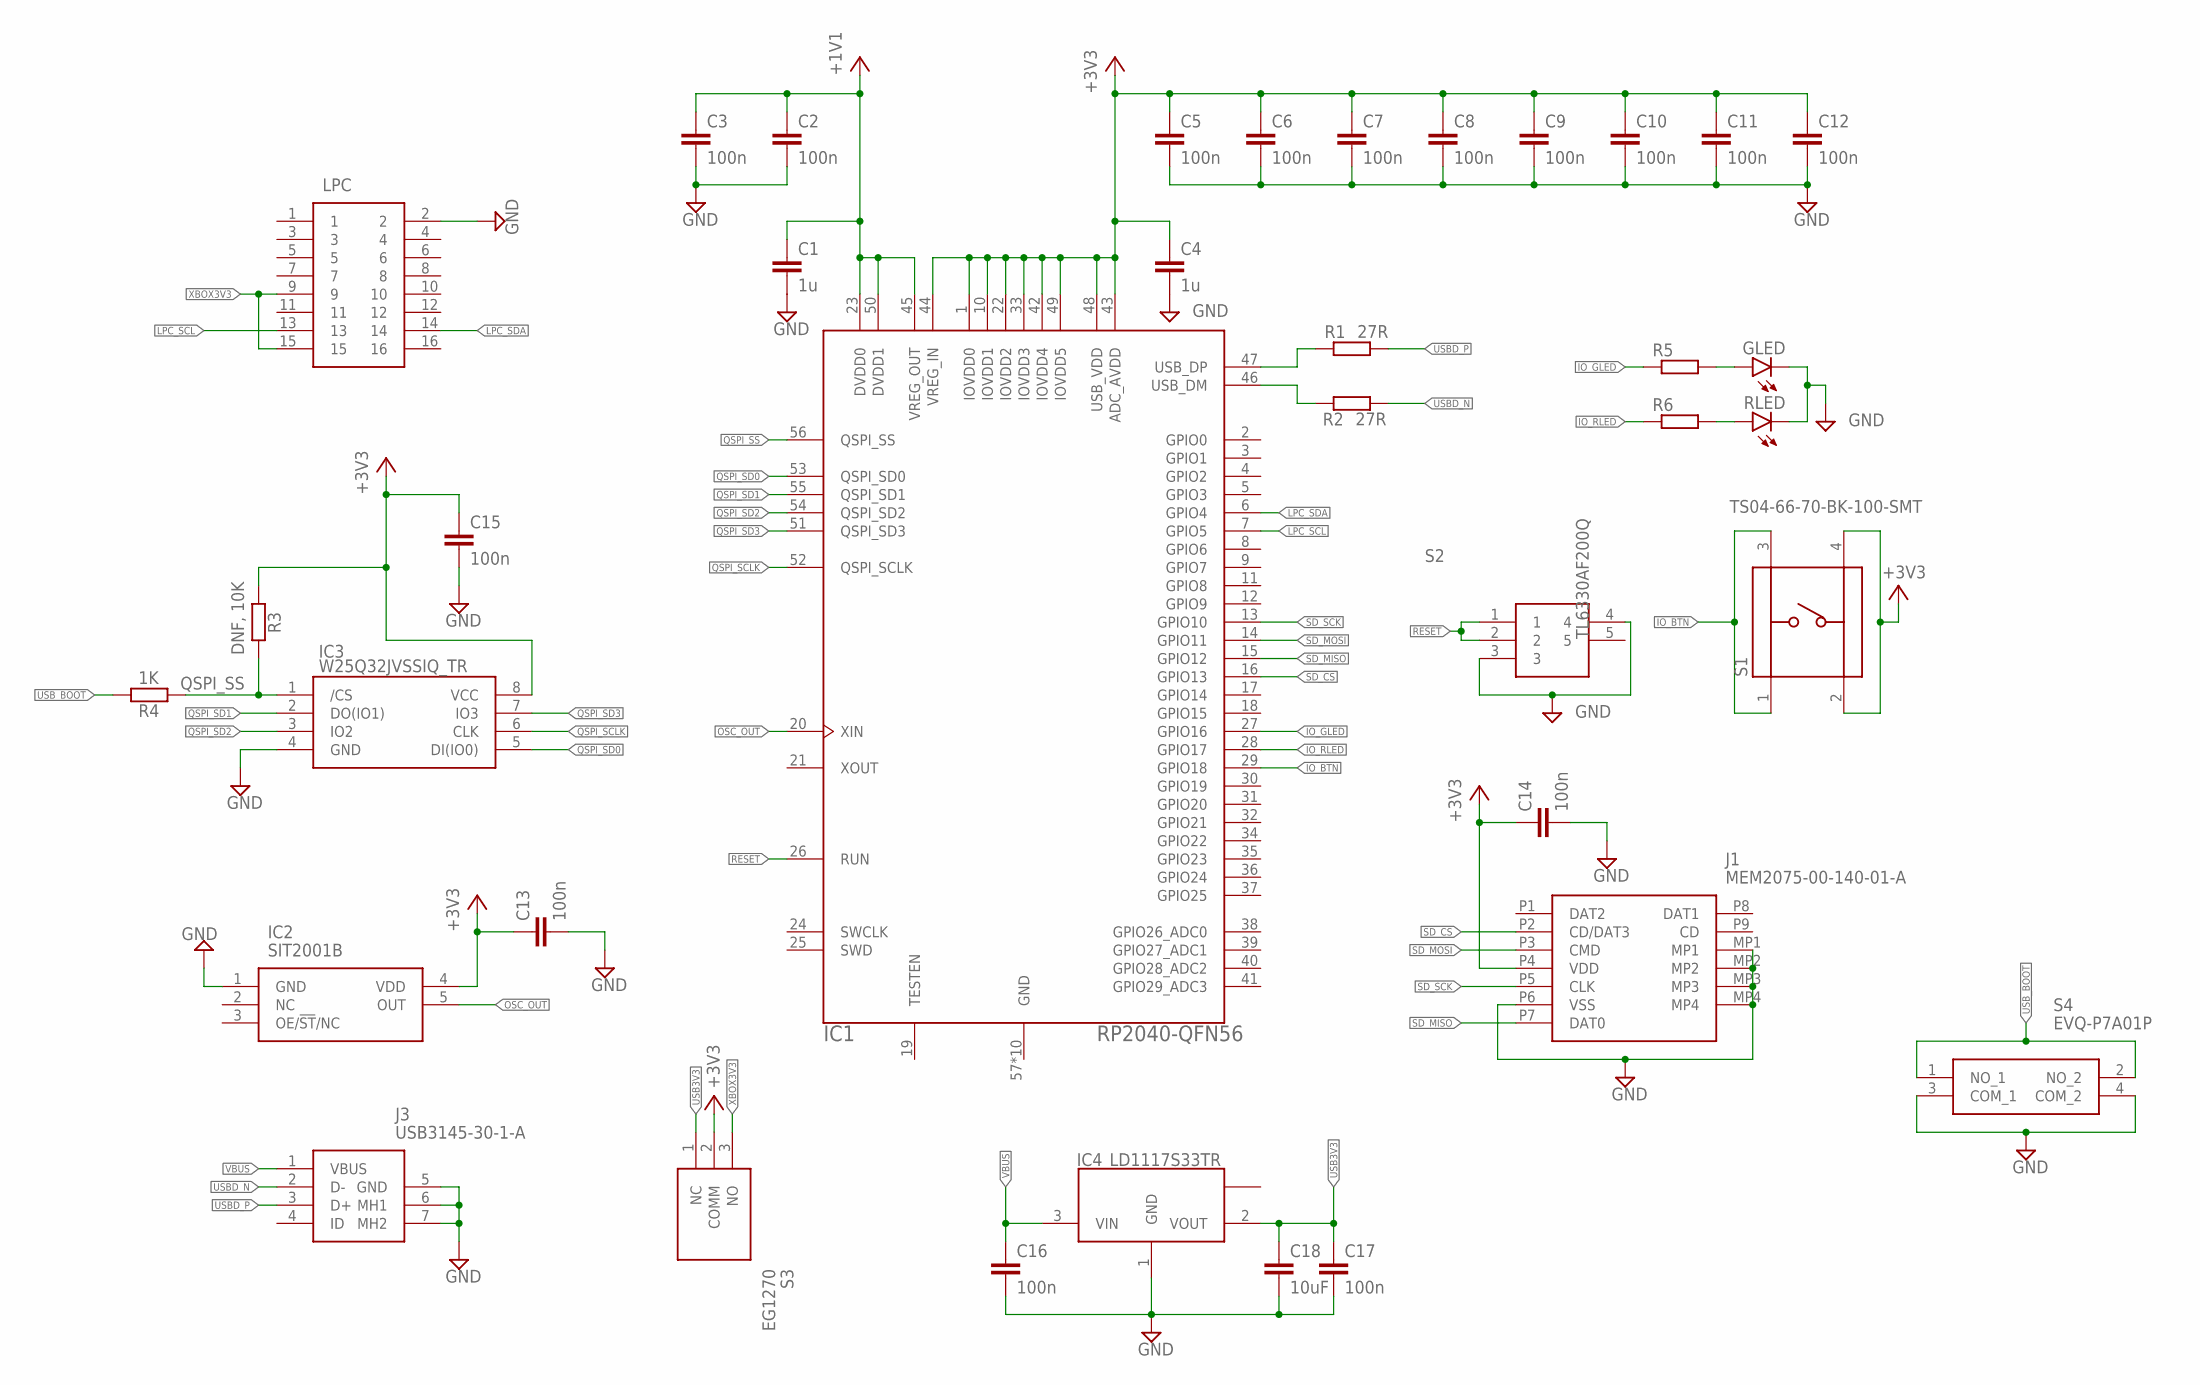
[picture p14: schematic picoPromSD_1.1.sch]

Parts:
C1, C4: 1u; C0402
C2, C3, C5, C6, C7, C8, C9, C10, C11, C12, C13, C14, C15, C16, C17: 100n; C0402
C18: 10uF; C0603
GLED: LED_LEDGREEN; GHI-BASICCOMPONENTS_0805-LED
IC1: RP2040-QFN56; RP2040-QFN-56
IC2: SIT2001B; SOT95P280X130-5N
IC3: W25Q32JVSSIQ_TR; SOIC127P790X216-8N
IC4: LD1117S33TR; SOT223
J1: MEM2075-00-140-01-A; MEM20750014001A
J3: USB3145-30-1-A; USB3145301A
LPC: 61301621821; RHDR16W79P254X254_2X8_2082X508
R1, R2: 27R; R0402
R3: DNF, 10K; R0402
R4: 1K; R0402
R5, R6: R-EU_R0402; R0402
RLED: LED_LEDRED; CHIP-LED0805
S1: TS04-66-70-BK-100-SMT; SW_TS04-66-70-BK-100-SMT
S2: TL6330AF200Q
S3: EG1270
S4: EVQ-P7A01P; EVQP7J01P

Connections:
+3V3: C4.1, C5.1, C6.1, C7.1, C8.1, C9.1, C10.1, C11.1, C12.1, C13.1, C14.1, C15.1, IC1.1 (IOVDD0), IC1.10 (IOVDD1), IC1.22 (IOVDD2), IC1.33 (IOVDD3), IC1.42 (IOVDD4), IC1.43 (ADC_AVDD), IC1.44 (VREG_IN), IC1.48 (USB_VDD), IC1.49 (IOVDD5), IC2.4 (VDD), IC3.8 (VCC), J1.P4 (VDD), R3.2, S1.2, S1.4, S3.2 (COMM)
GND: C1.2, C2.2, C3.2, C4.2, C5.2, C6.2, C7.2, C8.2, C9.2, C10.2, C11.2, C12.2, C13.2, C14.2, C15.2, C16.2, C17.2, C18.2, GLED.K (C), IC1.57 (GND), IC1.58 (GND), IC1.59 (GND), IC1.60 (GND), IC1.61 (GND), IC1.62 (GND), IC1.63 (GND), IC1.64 (GND), IC1.65 (GND), IC1.66 (GND), IC2.1 (GND), IC3.4 (GND), IC4.1 (GND), J1.MP1, J1.MP2, J1.MP3, J1.MP4, J1.P6 (VSS), J3.5 (GND), J3.6 (MH1), J3.7 (MH2), LPC.2, RLED.C, S2.3, S2.4, S4.3 (COM_1), S4.4 (COM_2)
IO_BTN: IC1.29 (GPIO18), S1.1, S1.3
IO_GLED: IC1.27 (GPIO16), R5.1
IO_RLED: IC1.28 (GPIO17), R6.1
LPC_SCL: IC1.7 (GPIO5), LPC.13
LPC_SDA: IC1.6 (GPIO4), LPC.14
unnamed: GLED.A, R5.2
unnamed: R6.2, RLED.A
OSC_OUT: IC1.20 (XIN), IC2.5 (OUT)
PUSBD_N: IC1.46 (USB_DM), R2.1
PUSBD_P: IC1.47 (USB_DP), R1.1
QSPI_SCLK: IC1.52 (QSPI_SCLK), IC3.6 (CLK)
QSPI_SD0: IC1.53 (QSPI_SD0), IC3.5 (DI(IO0))
QSPI_SD1: IC1.55 (QSPI_SD1), IC3.2 (DO(IO1))
QSPI_SD2: IC1.54 (QSPI_SD2), IC3.3 (IO2)
QSPI_SD3: IC1.51 (QSPI_SD3), IC3.7 (IO3)
QSPI_SS: IC1.56 (QSPI_SS), IC3.1 (/CS), R3.1, R4.2
RESET: IC1.26 (RUN), S2.1, S2.2
SD_CS: IC1.16 (GPIO13), J1.P2 (CD/DAT3)
SD_MISO: IC1.15 (GPIO12), J1.P7 (DAT0)
SD_MOSI: IC1.14 (GPIO11), J1.P3 (CMD)
SD_SCK: IC1.13 (GPIO10), J1.P5 (CLK)
USB3V3: C17.1, C18.1, IC4.2 (VOUT), S3.1 (NC)
USBD_N: J3.2 (D-), R2.2
USBD_P: J3.3 (D+), R1.2
USB_BOOT: R4.1, S4.1 (NO_1), S4.2 (NO_2)
VBUS: C16.1, IC4.3 (VIN), J3.1 (VBUS)
VCC: C1.1, C2.1, C3.1, IC1.23 (DVDD0), IC1.45 (VREG_OUT), IC1.50 (DVDD1)
XBOX3V3: LPC.9, LPC.15, S3.3 (NO)

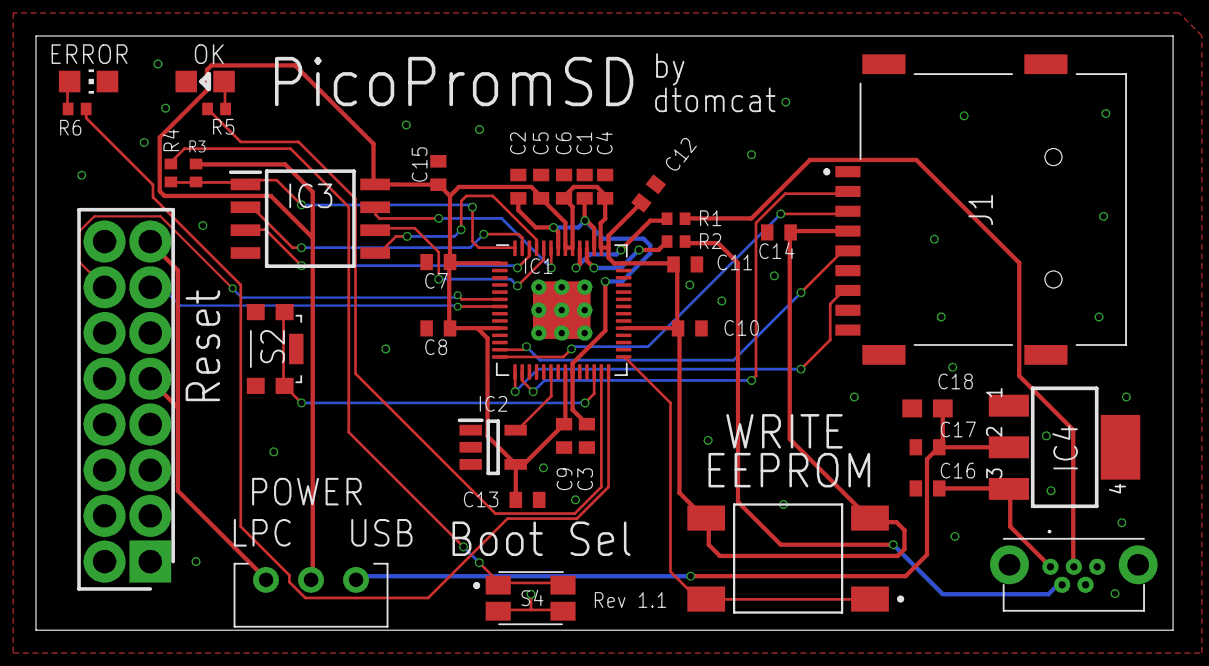
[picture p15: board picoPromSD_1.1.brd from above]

Board: 2 copper layers, 63.2 x 33.0 mm, 37 parts (0 on the bottom side), 30 nets.

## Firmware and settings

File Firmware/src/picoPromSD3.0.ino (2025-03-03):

#define XBOX_EEPROM_ADDRESS 0x54
#define XBOX_EEPROM_SIZE    256
#define GLED                16
#define RLED                17
#define BUTT                18 

extern "C" void flash_get_unique_id(uint8_t *p);

//********************************************
//**********    COMPILE OPTIONS     ********** 
//********************************************
bool noDelay = false;            //Used to remove delay that is used to allow time for a serial connection
bool verboseMode = false;       //Display all HDD terminal info?
const char ver[] = "3.0";       //Firmware Version constant 
//********************************************
//********************************************
//********************************************


//SD card pin assignment
const int _MISO = 12;
const int _MOSI = 11;
const int _CS = 13;
const int _SCK = 10;
//End SD card pin assignment

//HDD Delay Constants
const int slimDelay = 8000;
const String slimText = "8 sec";
const int rjDelay = 5000;
const String rjText = "5 sec";
//End HDD Delay Cosntants

const int logPrint = 1;         //Definitions for serialLog function
const int logPrintln = 2;       //Definitions for serialLog function
String deSerial;
uint8_t UniqueID[8];            //Holds PicoPromSD's Serial Number

//variables for Seagate Password routines
byte r1, r2, r3, r4, r5, r6, r7, r8, r9, r10, r11, r12, r13, r14;
char lockBit = 0;
char conRx;                     //General CHAR variable
bool ErrDet = false;            //Error Flag
bool isSlim = true;             //True if Slim, False if Rubber
String HDDPW = "";              //Holds HDD Password
String HDDSN = "";              //Holds HDD Serial Number
const int slim = 0;
const int rubber = 1;
//----------------------------------------

#include <Wire.h>
#include <SPI.h>
#include <SD.h>
#include "sha1.hpp"
#include "xbox.hpp"
#include "HMAC_SHA1.h"

File logFile;
bool isLogFile = false;
bool hddPassFile = false;
bool grabPassOnly = false;
bool unlockSeagate = false;
String SN = "";

char pbEEPROM[XBOX_EEPROM_SIZE];
char deEEPROM[XBOX_EEPROM_SIZE];
byte driveData[40] = {0};
int xversion = -1;
int rlen = 0;

void setup() {
  pinMode(GLED, OUTPUT);
  pinMode(RLED, OUTPUT);
  pinMode(BUTT, INPUT_PULLDOWN);
  digitalWrite(GLED, HIGH); //Green LED on
  digitalWrite(RLED, HIGH); //Red LED on
  //Check if HDD Password mode is desired
  if (digitalRead(BUTT)){
    grabPassOnly = true;
    dance(5);
    //Check if HDD unlock mode is desired
    if (digitalRead(BUTT)){
      unlockSeagate = true;
      danceFast(5);
    }
  }
  SPI1.setRX(_MISO);
  SPI1.setTX(_MOSI);
  SPI1.setSCK(_SCK);
  Serial.begin(115200);
  Serial.println("Serial1 is active");
  if (!noDelay){
    delay(5000);
  }
  if (!grabPassOnly){
    Wire.begin();
  }else{
    Serial.println("Setting up Serial2");
    Serial2.setTX(4);
    Serial2.setRX(5);
    Serial2.begin(9600);
  }
  flash_get_unique_id(UniqueID);          //Grab PicoPromSD's Serial Number and store it in UniqueID
  Serial.print("Initializing SD card...");
  //Initialize SD card then check for folder... 
  //if doesn't exist; create it
  if (!SD.begin(_CS, SPI1)) {
    delay(100);
    setError();
    serialLog(logPrintln, "*********************************************");
    serialLog(logPrintln, "SD Card Initialization Failed!");
    serialLog(logPrintln, "*********************************************");
    endProgram();
  }
  serialLog(logPrintln, "OK");
  serialLog(logPrintln, "Checking for \"epbackup\" folder...");
  if (!SD.exists("epbackup")){
    serialLog(logPrintln, "epbackup doesn't exist...  creating it");
    if (!SD.mkdir("epbackup")) {
      setError();
      serialLog(logPrintln, "*********************************************");
      serialLog(logPrintln, "Error creating epbackup folder");
      serialLog(logPrintln, "*********************************************");
      endProgram();
    }
  }
  serialLog(logPrintln, "OK");
  
  serialLog(logPrintln, "Checking for \"HDDPass\" folder...");
  if (!SD.exists("HDDPass")){
    serialLog(logPrintln, "HDDPass doesn't exist...  creating it");
    if (!SD.mkdir("HDDPass")) {
      setError();
      serialLog(logPrintln, "*********************************************");
      serialLog(logPrintln, "Error creating HDDPass folder");
      serialLog(logPrintln, "*********************************************");
      endProgram();
    }
  }
    serialLog(logPrintln, "OK");
  
  //*************************************************
  //Check for file that holds data needed for HDD Password
  //*************************************************
  if (SD.exists("epbackup/driveinfo.txt") && !grabPassOnly){
    serialLog(logPrintln, "Driveinfo.txt is present!  Will attempt to provide HDD password.");
    //Open file for read
    File HDDpass = SD.open("epbackup/driveinfo.txt", FILE_READ);
    if (HDDpass){
      rlen = HDDpass.available();
      byte driveDataTemp[rlen];
      int returnStatus = -1;
      returnStatus = HDDpass.read(driveDataTemp, sizeof(driveDataTemp));
      hddPassFile = true;
      for (int aa = 0; aa < sizeof(driveDataTemp); aa++){
        driveData[aa] = driveDataTemp[aa];
      }
    }
    HDDpass.close();
  }
  serialLog(logPrintln, "Attempting to create log file...");
  String logFileName = "";
  if (!grabPassOnly){
    logFileName = getFileName("output", "log");
  } else {
    logFileName = getFileNameHDD("output", "log");
  }
  logFile = SD.open(logFileName, FILE_WRITE);
  // if the file opened okay, write to it:
  if (logFile) {
    serialLog(logPrintln, "OK");
    serialLog(logPrintln, "All Further information will also appear in the LOG");
    isLogFile = true;
  } else {
    serialLog(logPrintln, "*****************************************************************");
    serialLog(logPrintln, "Error creating log file!  Attempting to continue without logging.");
    serialLog(logPrintln, "*****************************************************************");
    isLogFile = false;    
  }
  
  //**************************************************
  //Send everything to try to get logged from now on.
  //**************************************************
  printVer();
  if (grabPassOnly) {
    HDDPassGrab();
  }
  serialLog(logPrint, "Trying to communicate with Xbox EEPROM...");
  //Check for communication with EEPROM
  int returnStatus = -1;
  returnStatus = XboxI2C_DetectEEPROM(XBOX_EEPROM_ADDRESS);
  if (returnStatus == -1) {
    setError();
    serialLog(logPrintln, "");
    serialLog(logPrintln, "**********************************************************************");
    serialLog(logPrintln, "Error - EEPROM not detected.  Please check wires and ensure Xbox is on");
    serialLog(logPrintln, "**********************************************************************");
    endProgram();
  }
  serialLog(logPrintln, "OK");
  serialLog(logPrintln, "Attempting to get EEPROM data...");
  //Grab EEPROM and decrypt it
  String fname = "";
  returnStatus = XboxI2C_ReadEEPROM(XBOX_EEPROM_ADDRESS, pbEEPROM);
  if (returnStatus != -1) {
    serialLog(logPrintln, "EEPROM data successful... Attempting to decrypt");
    serialLog(logPrint, "CRC of EEPROM Data: "); String crc = checksumCalculator((uint8_t*) pbEEPROM, XBOX_EEPROM_SIZE);serialLog(logPrintln, crc);
    memcpy(deEEPROM, pbEEPROM, XBOX_EEPROM_SIZE);
    serialLog(logPrint, "CRC of copied EEPROM Data: "); crc = checksumCalculator((uint8_t*) deEEPROM, XBOX_EEPROM_SIZE); serialLog(logPrintln, crc);
    XboxCrypto *xbx = new XboxCrypto();
    if (xbx->decrypt((unsigned char *)deEEPROM) >= 0) {
       serialLog(logPrintln, "EEPROM Decrypt Successful!");
       xversion = xbx->getVersion();
       SN = getSerialNum();
       //Get filename for txt file
       fname = getFileName(getSerialNum(), "txt", SN);
       bool fileResult = writeTXT(fname);
       if (!fileResult){
        serialLog(logPrintln, "Txt Not written");
       }
       serialLog(logPrint, "CRC of Decrypted EEPROM Data: "); crc = checksumCalculator((uint8_t*) deEEPROM, XBOX_EEPROM_SIZE); serialLog(logPrintln, crc);
       serialLog(logPrintln, "Xbox Version: " + xboxVerLookup(xversion));
       serialLog(logPrintln, "Online Key: " + getOnlineKey());
       serialLog(logPrintln, "HDD Key: " + getHDDkey());
       if (hddPassFile) serialLog(logPrintln, "HDD Pass: " + getHDDPassword());
       serialLog(logPrintln, "Confounder: " + getConfounder());
       serialLog(logPrintln, "Region: " + getRegion());
       serialLog(logPrintln, "MAC: " + getMAC());
       serialLog(logPrintln, "Serial: " + getSerialNum());
       serialLog(logPrintln, "Video Standard: " + getVideoStd());
       serialLog(logPrintln, "DVD Zone: " + getDVDRegion());
      }
      else {
        serialLog(logPrintln, "********************************************************************");
        serialLog(logPrintln, "Error - Decryption Failed.  Continuing with save and write fuctions!");
        serialLog(logPrintln, "********************************************************************");
      }
  }else
  {
    setError();
    serialLog(logPrintln, "****************************************************************************");
    serialLog(logPrintln, "Error - Failed to get EEPROM data.  Please check wires and ensure Xbox is on");
    serialLog(logPrintln, "****************************************************************************");
    endProgram();
  }
  

  
  //create eeprom.bin and read eeprom from xbox and
  //dump into eeprom.bin
  String filename;
  if (fname == ""){
    filename = getFileName("eeprom", "bin", SN);
  } else {
    filename = getFileName(getSerialNum(), "bin", SN);
  }
  serialLog(logPrintln, "Attempting to create: " + filename + " ...");
  File myFile = SD.open(filename, FILE_WRITE);
  // if the file opened okay, write to it:
  if (myFile) {
    returnStatus = myFile.write(pbEEPROM, XBOX_EEPROM_SIZE);
    if (!returnStatus) {
      setError();
      serialLog(logPrintln, "***********************************************************************");
      serialLog(logPrintln, "Failed to write EEPROM Data to " + filename + ".  Please check SD card!");
      serialLog(logPrintln, "EEPROM is NOT backed up!!!!");
      serialLog(logPrintln, "***********************************************************************");
      myFile.close();
      endProgram();
    }
    // close the file:
    myFile.close();
    setOK();
    serialLog(logPrintln, "SUCCESS!");
  }
  else {
    setError();
    serialLog(logPrintln, "******************************************************");
    serialLog(logPrintln, "ERROR creating eeprom.bin file.  Please check SD card!");
    serialLog(logPrintln, "EEPROM is NOT backed up!!!!");
    serialLog(logPrintln, "******************************************************");
    endProgram();
  }
  //Clear EEPROM data from memory
  memset(pbEEPROM, 0, XBOX_EEPROM_SIZE); 
}

void loop(){
  int returnStatus = -1;
  int buttonState = digitalRead(BUTT); //Button Status
  serialLog(logPrint, "Write EEPROM button State: ");serialLog(logPrintln, (String)buttonState);
  //Check if eeprom.bin in writeep folder to write to EEPROM
  //If so, let user know it's ready to write (blinking Green LED)
  //if not, halt program
  if (SD.exists("writeep/eeprom.bin"))
  {
    serialLog(logPrintln, "eeprom.bin found in writeep folder!");
    File ckFile = SD.open("writeep/eeprom.bin", FILE_READ);
    serialLog(logPrint, "writeep/eeprom.bin size = ");
    serialLog(logPrintln, String(ckFile.size()));
    memset(pbEEPROM, 0, XBOX_EEPROM_SIZE);
    memset(deEEPROM, 0, XBOX_EEPROM_SIZE);
    if (ckFile.size() != 256)
    {
      serialLog(logPrintln, "*********************************************");
      serialLog(logPrintln, "writeep/eeprom.bin is wrong file size. Write cannot be performed");
      serialLog(logPrintln, "*********************************************");
      endProgramError();
    }
    serialLog(logPrintln, "attempting to read writeep/eeprom.bin and decrypt");
    returnStatus = ckFile.read((uint8_t*) pbEEPROM, XBOX_EEPROM_SIZE);
    if (returnStatus){
      memcpy(deEEPROM, pbEEPROM, XBOX_EEPROM_SIZE);
      XboxCrypto *xbx2 = new XboxCrypto();
      if (xbx2->decrypt((unsigned char *)deEEPROM) >= 0) {
       serialLog(logPrintln, "EEPROM Decrypted successfully!");
      } else {
        serialLog(logPrintln, "*********************************************");
        serialLog(logPrintln, "writeep/eeprom.bin was not able to be decrypted. For safety, write cannot be performed");
        serialLog(logPrintln, "*********************************************");
        endProgramError();
      }
    } else {
      serialLog(logPrintln, "*********************************************");
      serialLog(logPrintln, "writeep/eeprom.bin was not able to be read. Write cannot be performed");
      serialLog(logPrintln, "*********************************************");
      endProgramError();
    }
    ckFile.close();
    serialLog(logPrintln, "All checks passed, waiting for button press to write EEPROM...");
    while (!buttonState) {
      digitalWrite(GLED, !digitalRead(GLED));
      buttonState = digitalRead(BUTT);
      delay(100);
    }
    digitalWrite(GLED, HIGH);
    digitalWrite(RLED, HIGH);
    
    //Write bin to EEPROM
    memset(pbEEPROM, 0, XBOX_EEPROM_SIZE);
    File myFile = SD.open("writeep/eeprom.bin", FILE_READ);
    returnStatus = myFile.read((uint8_t*) pbEEPROM, XBOX_EEPROM_SIZE);
    serialLog(logPrint, "CRC ToEEPROM: ");
    String crc = checksumCalculator((uint8_t*) pbEEPROM, XBOX_EEPROM_SIZE);
    serialLog(logPrintln, crc);
    //Check if file read
    if (returnStatus) {
      serialLog(logPrintln, "EEPROM data read from SD card.  Attempting to write to EEPROM...");
      returnStatus = XboxI2C_WriteEEPROM(XBOX_EEPROM_ADDRESS, pbEEPROM);
      //Check if write was successful
      if (returnStatus != -1) {
        myFile.close();
        serialLog(logPrintln, "Written Successfully!  Erasing eeprom.bin");
        //After successful write... remove file
        SD.remove("writeep/eeprom.bin");
        serialLog(logPrintln, "eeprom.bin has been erased from writeep folder.");
        setOK();
        serialLog(logPrintln, "*********************************************");
        serialLog(logPrintln, "Backup and Write processes completed successfully");
        serialLog(logPrintln, "Restart module to run again!");
        serialLog(logPrintln, "*********************************************");
        endProgram();
      } else {
        serialLog(logPrintln, "*********************************************");
        serialLog(logPrintln, "Error writing eeprom.bin to EEPROM!  Check wires and try again.");
        serialLog(logPrintln, "*********************************************");
        setError();
        myFile.close();
        endProgram();
      }
    } else {
      setError();
      serialLog(logPrintln, "*********************************************");
      serialLog(logPrintln, "Error reading eeprom.bin from SD card!");
      serialLog(logPrintln, "*********************************************");
      myFile.close();
      while(1);
    }
  } else {
      serialLog(logPrintln, "*********************************************");
      serialLog(logPrintln, "Write files not present... Program ended!");
      serialLog(logPrintln, "Restart module to try again!");
      serialLog(logPrintln, "*********************************************");
    endProgram();
  }
}

//********************************************
//**********    END of MAIN CODE    **********
//**********    CUSTOM FUNCTIONS    ********** 
//********************************************

// Sets LEDs to indicate a bad result
void setError() {
  digitalWrite(RLED, HIGH); //Red LED on
  digitalWrite(GLED, LOW);  //Green LED off
}

// Sets LEDs to busy state
void setBusy() {
  digitalWrite(RLED, HIGH); //Red LED on
  digitalWrite(GLED, HIGH);  //Green LED on
}

// Sets LEDs to indicate Good result dimly (ONLY FOR TESTING)************************************************************
void setOKdim() {
  digitalWrite(RLED, LOW); //Red LED off
  analogWrite(GLED, 20);  //Green LED on
}

// Sets LEDs to indicate Good result
void setOK() {
  digitalWrite(RLED, LOW); //Red LED off
  digitalWrite(GLED, HIGH);  //Green LED on
}

// Alternating LEDs
void dance(int times) {
  for (int t = 0; t < times; t++){
    digitalWrite(RLED, LOW);
    digitalWrite(GLED, HIGH);
    delay(500);
    digitalWrite(RLED, HIGH);
    digitalWrite(GLED, LOW);
    delay(500);
  }
  digitalWrite(RLED, LOW);
  digitalWrite(GLED, LOW);
}

// Alternating LEDs Faster
void danceFast(int times) {
  for (int t = 0; t < times; t++){
    digitalWrite(RLED, LOW);
    digitalWrite(GLED, HIGH);
    delay(250);
    digitalWrite(RLED, HIGH);
    digitalWrite(GLED, LOW);
    delay(250);
  }
  digitalWrite(RLED, LOW);
  digitalWrite(GLED, LOW);
}

// prints Header into each Log
void printVer() {
  serialLog(logPrintln,"      PicoPromSD");
  serialLog(logPrintln,"======================");
  serialLog(logPrint,"==   Version: ");
  serialLog(logPrint, ver);
  serialLog(logPrintln, "   ==");
  serialLog(logPrint,"== ");
  printPSN();
  serialLog(logPrintln, " ==");
  serialLog(logPrintln,"======================");
}

// Generates checksum
String checksumCalculator(uint8_t * data, uint16_t length)
{
   char buffers[16];
   String result;
   uint16_t curr_crc = 0x0000;
   uint8_t sum1 = (uint8_t) curr_crc;
   uint8_t sum2 = (uint8_t) (curr_crc >> 8);
   int index;
   for(index = 0; index < length; index = index+1)
   {
      sum1 = (sum1 + data[index]) % 255;
      sum2 = (sum2 + sum1) % 255;
   }
   uint16_t crcRaw = (sum2 << 8) | sum1;
   sprintf(buffers, "%04X", crcRaw);
   result = buffers;
   return result;
}

// Returns xbox Version (1.0, 1.1-1.4, or 1.6)
String xboxVerLookup(int ver){
  String result;
  switch(ver){
    case 0:
      result = "1.0";
      break;
    case 1:
      result = "1.1 - 1.4";
      break;
    case 2:
      result = "1.6";
      break;
    default:
      result = "INVALID";
      break;
  }
  return result;
}

// Returns eeprom Region
String getRegion(){
  String result;
  unsigned char char1 = deEEPROM[44];
  unsigned char char4 = deEEPROM[47];
  switch(char1){
    case ((char) 0x00):
      if (char4 == (char) 0x80) result = "Manufacturing Plant"; else result = "INVALID 00";
      break;
    case ((char) 0x01):
      result = "North America";
      break;
    case ((char) 0x02):
      result = "Japan";
      break;
    case ((char) 0x04):
      result = "Europe/Australia";
      break;
    default:
      result = "INVALID";
      break;
  }
  return result;
}

// Returns eeprom Video Standard
String getVideoStd(){
  String result;
  unsigned char char2 = deEEPROM[89];
  unsigned char char3 = deEEPROM[90];
  switch(char2){
    case ((char) 0x00):
      if (char3 == (char) 0x00) result = "Not Set (INVALID)"; else result = "INVALID 00";
      break;
    case ((char) 0x01):
      if (char3 == (char) 0x40) result = "NTSC-M"; else result = "INVALID 01";
      break;
    case ((char) 0x02):
      if (char3 == (char) 0x40) result = "NTSC-J"; else result = "INVALID 02";
      break;
    case ((char) 0x03):
      if (char3 == (char) 0x80) result = "PAL-I"; else result = "INVALID 03";
      break;
    case ((char) 0x04):
      if (char3 == (char) 0x40) result = "PAL-M"; else result = "INVALID 04";
      break;
    default:
      result = "INVALID (no match)";
      break;
  }
  return result;
}

// Returns eeprom DVD region
String getDVDRegion(){
  String result;
  unsigned char char1 = deEEPROM[188];
  switch(char1){
    case ((char) 0x00):
      result = "None";
      break;
    case ((char) 0x01):
      result = "Region 1";
      break;
    case ((char) 0x02):
      result = "Region 2";
      break;
    case ((char) 0x03):
      result = "Region 3";
      break;
    case ((char) 0x04):
      result = "Region 4";
      break;
    case ((char) 0x05):
      result = "Region 5";
      break;
    case ((char) 0x06):
      result = "Region 6";
      break;
    default:
      result = "INVALID";
      break;
  }
  return result;
}

// Returns eeprom Serial Number
String getSerialNum(){
  String result;
  for (int i = 52; i <= 63; i++){
    result = result + deEEPROM[i];
  }
  return result;   
}

// Returns eeprom HDD Key
String getHDDkey(){
   char buffers[5];
   String result;
   for (int i = 28; i <= 43; i++){
    sprintf(buffers, "%02X", deEEPROM[i]);
    result = result + buffers;
   }  
   return result;
}

// Calculates the HDD Password based on driveinfo.txt and eeprom hdKey
String getHDDPassword(){
  char buffers[5];                                      //Local Variable for converting HEX HASH to string
  byte HDKey[16];                                       //Local Variable for HDKey
  String result;                                        //Local Variable to return results
  
  //Grab HDKey and store in local variable
  for (int i = 28; i <= 43; i++){
    HDKey[i-28] = deEEPROM[i];
  }  
  byte digest[20];                                      //Local Variable to store HEX HASH
  byte buff[rlen];                                      //Local Variable to store driveData
  
  //Grab Drive Data from Global variable.  Need to do this since Global is larger than we need.
  for(int j=0; j < rlen; j++){
    buff[j] = driveData[j];
  }
  
  CHMAC_SHA1 HMAC_SHA1;
  HMAC_SHA1.HMAC_SHA1(buff, sizeof(buff), HDKey, sizeof(HDKey), digest) ;
  
  //Convert Hex Hash to String
  for (int k = 0; k <= 19; k++){
    sprintf(buffers, "%02X", digest[k]);
    result = result + buffers;
  }
  return result;
}

// Returns eeprom Online Key
String getOnlineKey(){
   char buffers[5];
   String result;
   for (int i = 72; i <= 87; i++){
    sprintf(buffers, "%02X", deEEPROM[i]);
    result = result + buffers;
   }
   return result;
}
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

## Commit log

2024-12-13 Initial Hardware upload
    Uploading rev 1.1 (do not recommend building this rev)... Wait for 1.5H (soon... in testing)
    [Pin2PogoPico v3.stl, picoPromSD_1.1.brd, picoPromSD_1.1.sch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]
2025-01-02 1.5H upload
    Upload of Rev1.5H and all files necessary to make or have one assembled.
    [PicoPromSD_v1.5H_Digikey_BOM.xlsx, PicoPromSD_v1.5H_JLC_PCBA_BOM.xlsx, PicoPromSD_v1.5H_LCSC_THT_BOM.xlsx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]

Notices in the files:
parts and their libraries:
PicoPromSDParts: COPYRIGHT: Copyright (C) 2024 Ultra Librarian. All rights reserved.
